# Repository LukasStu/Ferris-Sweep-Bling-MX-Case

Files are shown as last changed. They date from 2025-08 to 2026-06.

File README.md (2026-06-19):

# Ferris Sweep Bling MX Case

Fully enclosed, parametric OpenSCAD case for the Ferris Sweep (MX), built for clean looks, practical assembly, and solid acoustics.

This project targets makers who already know keyboard basics, so the guide focuses on the case-specific decisions and build flow.

## V2.1.0 Highlights

- Complete architecture refactor with dedicated top and bottom trays.
- Gasket-mounted PCB via switch-plate tabs for better isolation and typing feel.
- Accessible USB-C opening without removing the case.
- Integrated slider and reset access support.
- Heat-set insert bottom mounting for repeatable service and teardown.

## Gallery

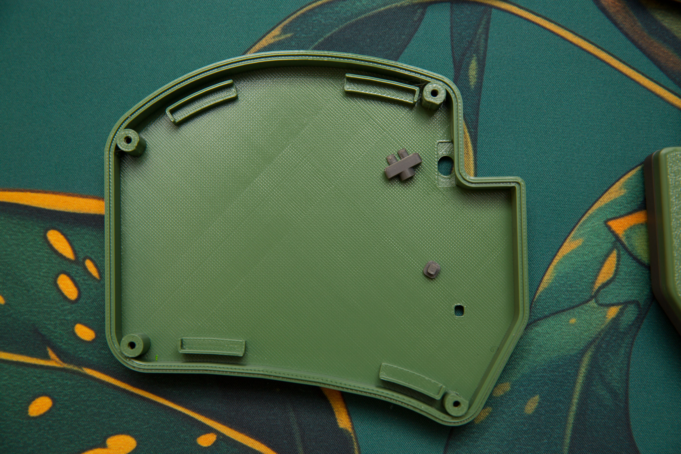
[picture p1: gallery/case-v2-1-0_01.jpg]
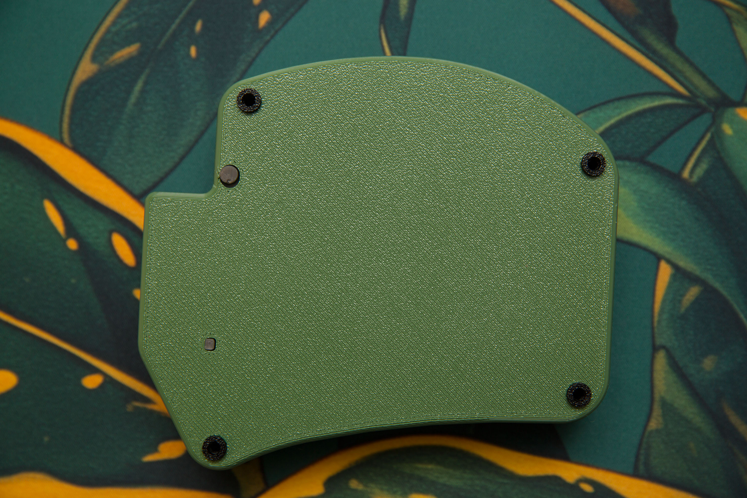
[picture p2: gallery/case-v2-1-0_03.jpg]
|  |  |
|---|---|
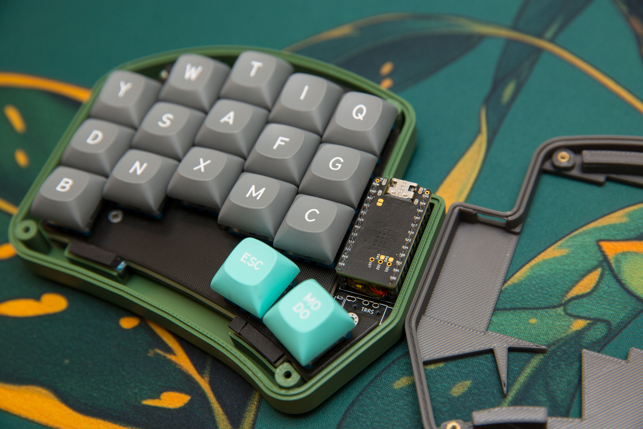
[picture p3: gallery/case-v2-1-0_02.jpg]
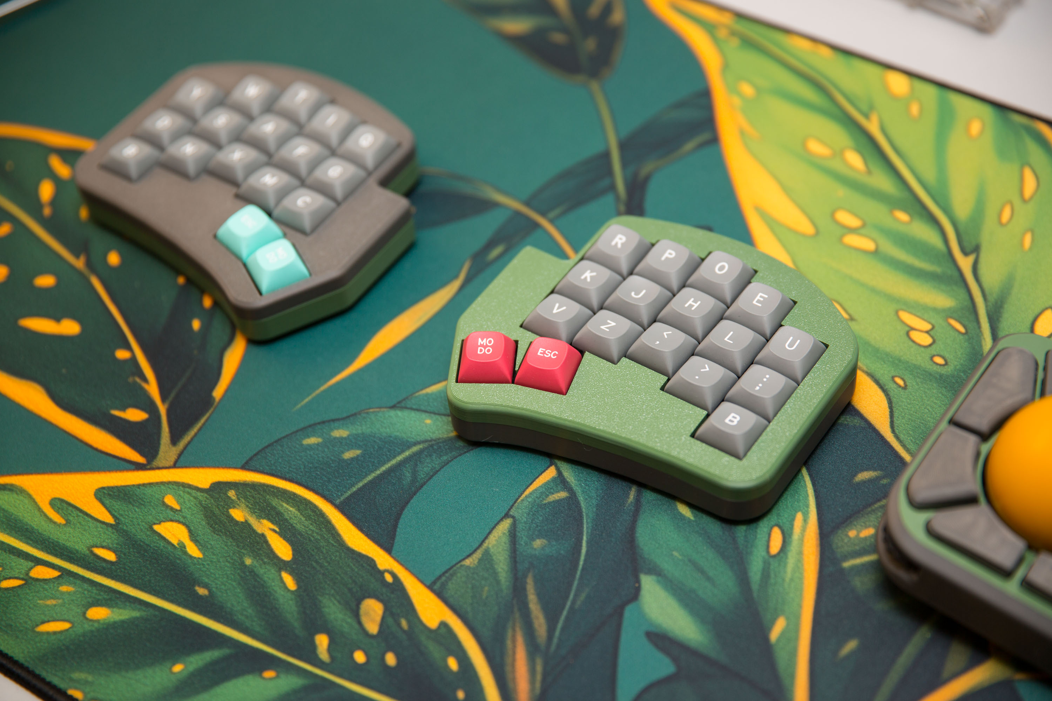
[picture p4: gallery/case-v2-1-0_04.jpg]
|  |  |
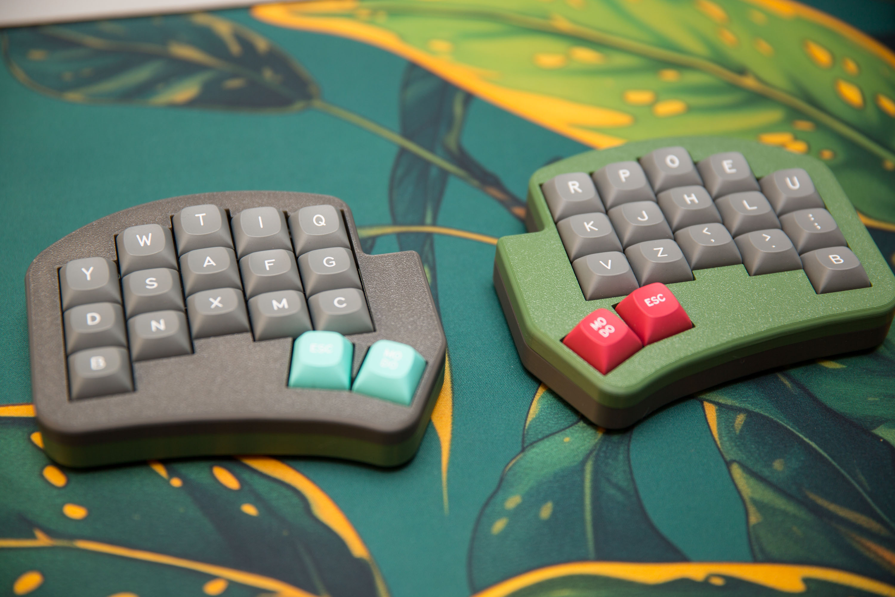
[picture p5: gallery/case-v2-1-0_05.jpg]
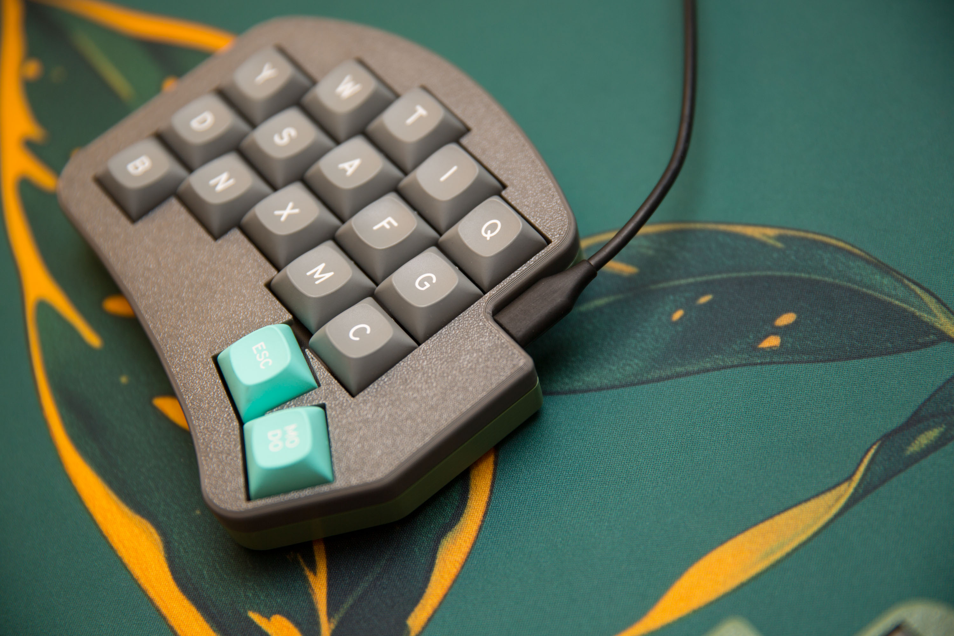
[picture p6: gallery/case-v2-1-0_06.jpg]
|  |  |

## MakerWorld

Download the latest release here:

[Ferris Sweep Bling MX Case v2.1.0 - MakerWorld](https://makerworld.com/de/models/2952710-ferris-sweep-bling-mx-case-v2-1-0#profileId-3308661)

## Repository Contents

- `case/case.scad` - main parametric model.
- `case/ferris_sweep_bling_mx.dxf` - reference 2D geometry.
- `gallery/` - build photos and reference images.

## Print Recommendations

- Material:
  - PLA/PETG for top and bottom case parts.
  - TPU for feet
- Supports:
  - Use tree supports on upper and lower parts for screw holes and USB opening.
- Usual quality baseline:
  - 0.2 mm layers, 1 to 2 walls, 15% to 25% infill.

## Hardware

- M2 heat-set inserts for the bottom mount points.
- Matching M2 screws for lid attachment.
- Ferris Sweep MX PCB including fr4 switchplate.

Heat-set and screw dimentions can be parameterized.

## Build Flow

1. Print case parts and clean support interfaces.
2. Install heat-set inserts in the top mounting points.
3. Test-fit PCB and confirm USB opening alignment before final assembly.
4. Close case with M2 screws and verify key travel/reset access.
5. Install TPU feet; Screws should still be accessable through hole.

## Wired Build Option

For a wired build, enable TRRS cutouts in both halves by uncommenting `trrs_cutout();` in:

- `top_case()`
- `bottom_case()`

If you are not using a power switch, comment out the power-switch cutouts.

## Adjusting USB Height and Outlet Alignment

USB-C position depends on your PCB/controller stack-up. In `case.scad`, two parameters control alignment:

### 1) `pcb_usb_distance`

- Definition: Distance in mm from PCB surface to USB-C port center.
- Purpose: Aligns the case outlet with the connector.
- How to measure: Measure from PCB top face to the middle of the USB-C shell.

<p align="center">
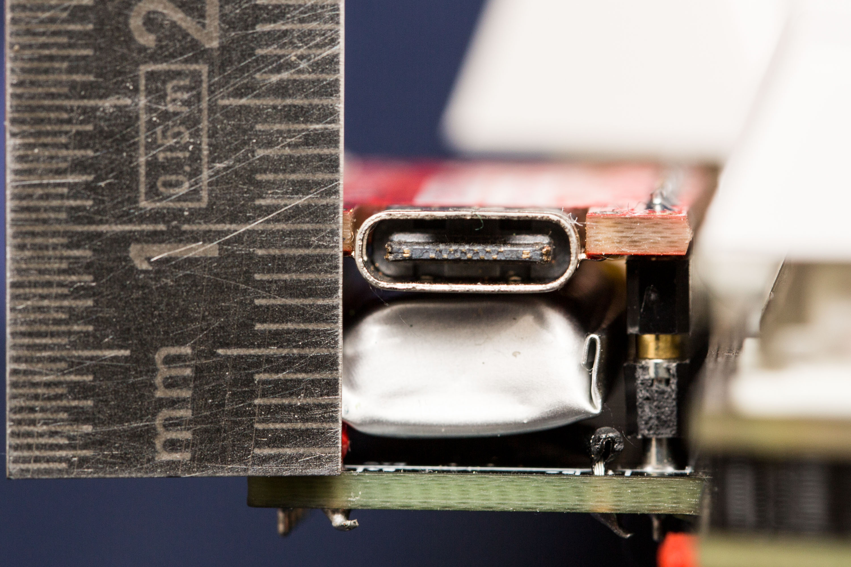
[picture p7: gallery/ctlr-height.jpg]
Measuring PCB to USB-C port distance
  <br>
  <em>Example: 9 mm from PCB to USB-C center</em>
</p>

### 2) `controller_wall_thickness` (optional)

- Definition: Wall thickness above the controller area near the USB opening.
- Default: `controller_wall_thickness = 1`.
- Use case: Increase if the wall is too thin for your controller placement.

### Parameter Example

```scad
pcb_usb_distance = 9;
controller_wall_thickness = 1.5;
```

Tip: print a short USB/controller test section first if your setup differs from common Ferris Sweep builds.

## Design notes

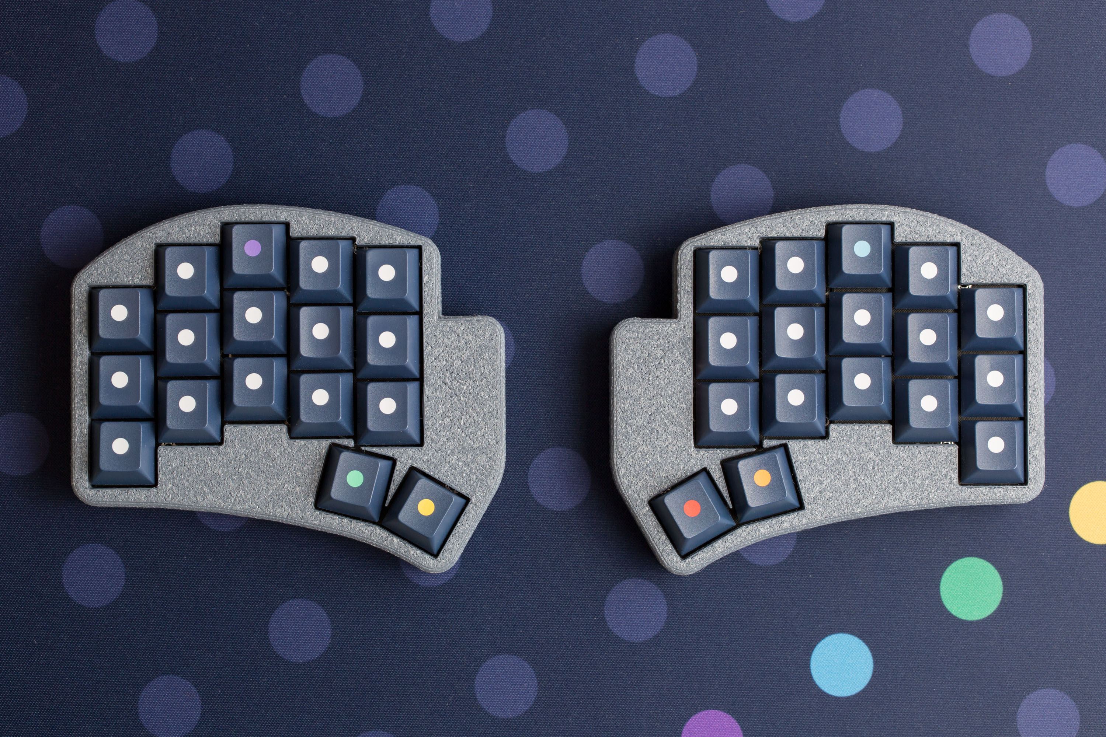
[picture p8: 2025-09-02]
gallery/case_05.jpg

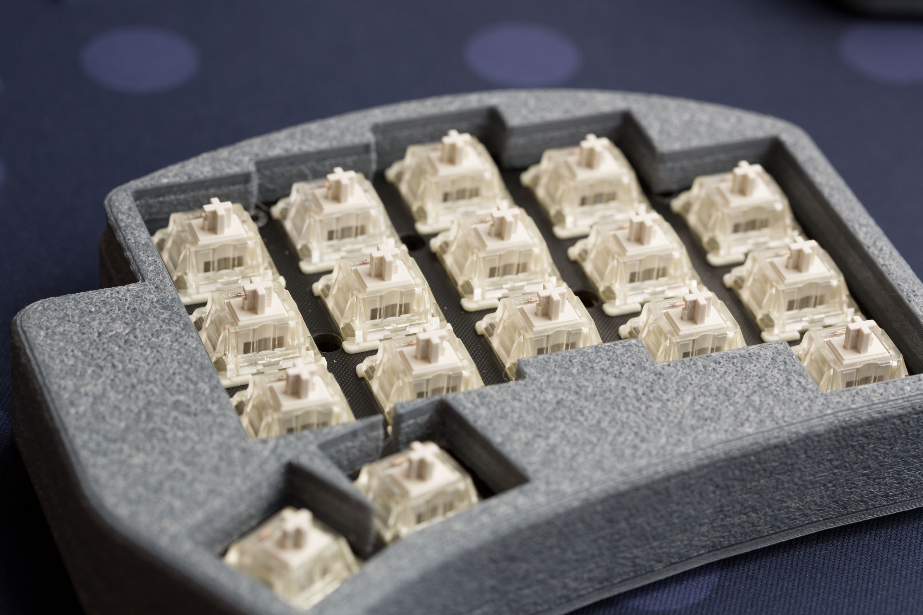
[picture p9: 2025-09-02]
gallery/case_04.jpg

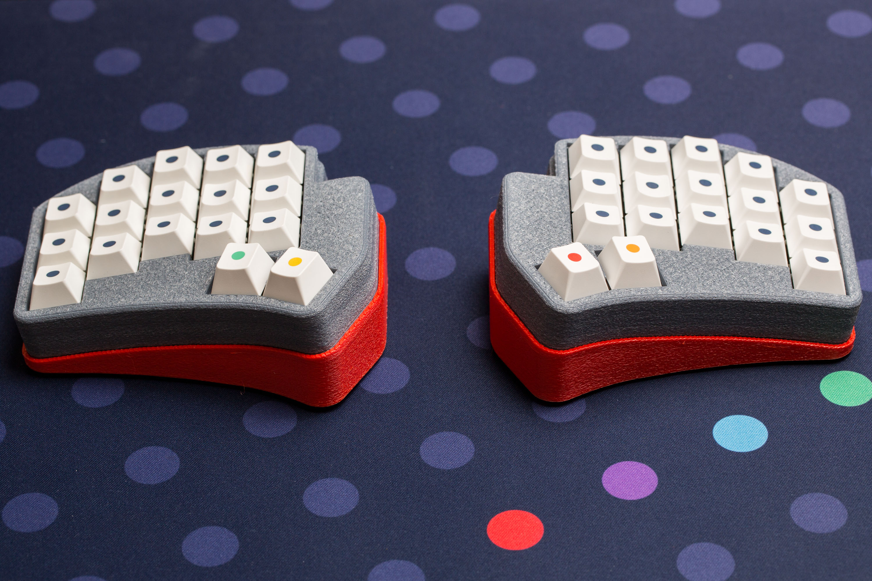
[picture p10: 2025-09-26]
gallery/tent_01.jpg

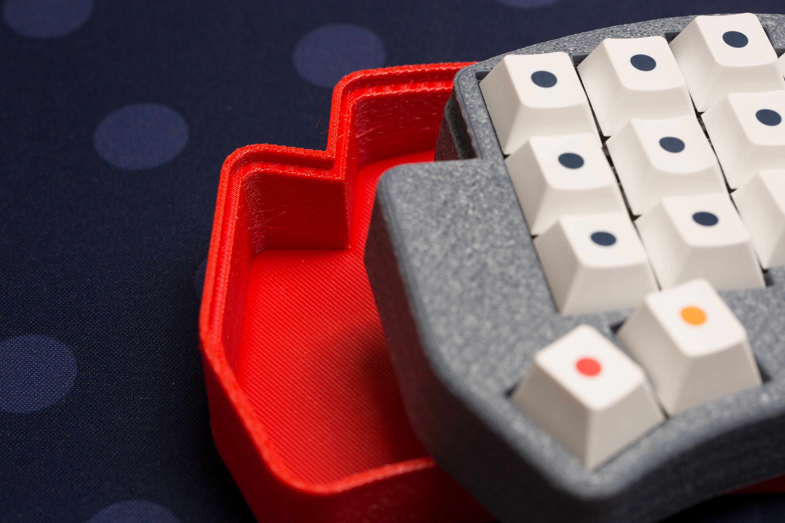
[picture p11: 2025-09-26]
gallery/tent_02.jpg

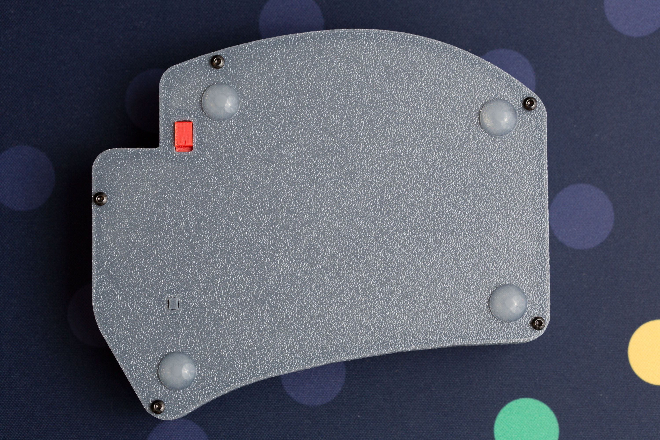
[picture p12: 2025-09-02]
gallery/case_03.jpg

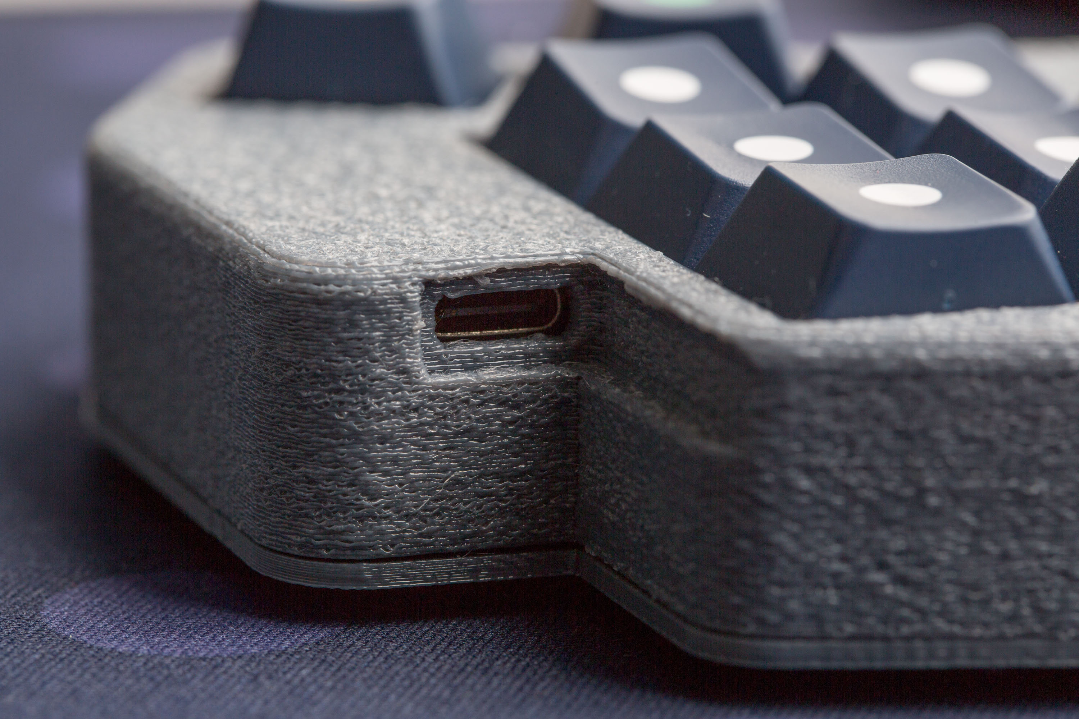
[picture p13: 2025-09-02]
gallery/case_02.jpg

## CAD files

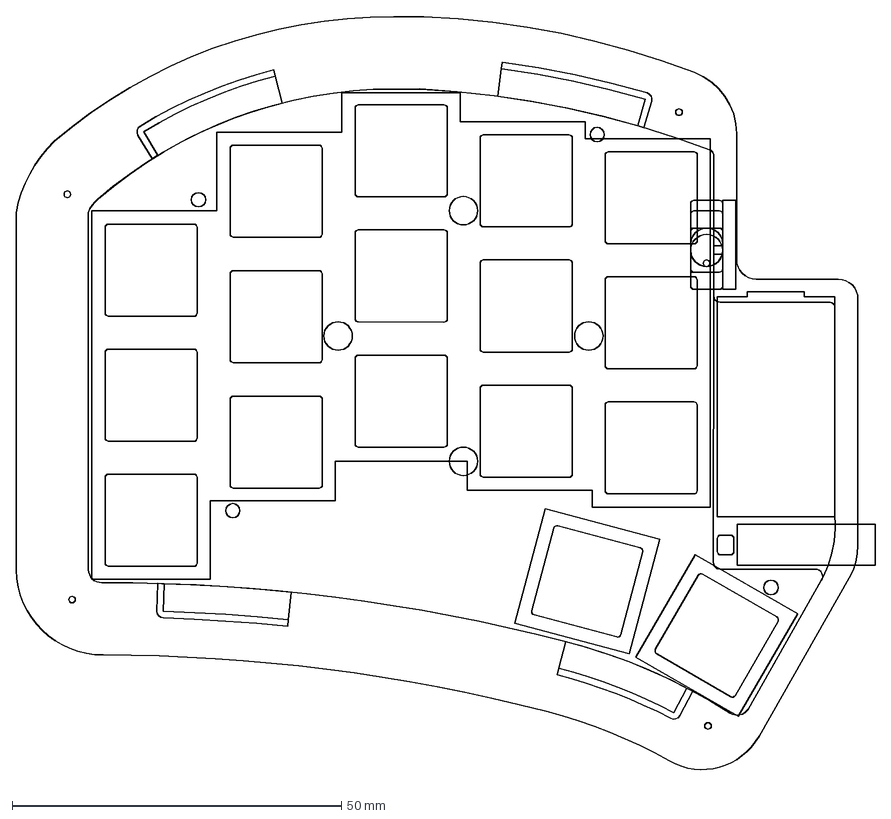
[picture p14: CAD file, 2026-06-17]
case/ferris_sweep_bling_mx.dxf
130.5 x 115.9 mm

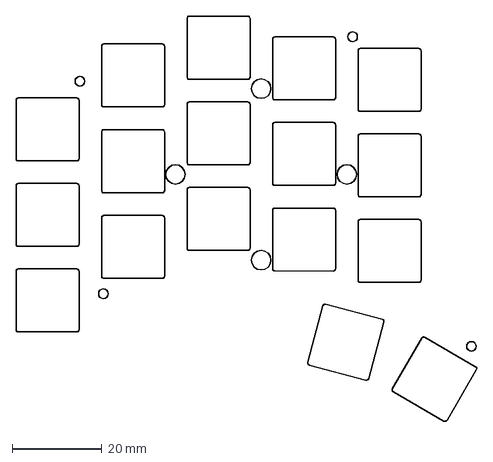
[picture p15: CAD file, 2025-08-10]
case/spacer/keys.dxf
102.4 x 90.1 mm

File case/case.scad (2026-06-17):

// -----------------------------------------------------------------------------
// Ferris Sweep MX Case Generator
// Author: Lukas Stürmlinger
// Requires: OpenSCAD 2021+ and ferris_sweep_bling_mx.dxf in the same directory.
// Description: Builds top/bottom shells, switch-plate foam, slider, reset button,
//              and optional tent support by extruding DXF layers via extrude_layer().
// Usage: Set PART to "top_case", "bottom_case", etc., then F6 to render.
// Notes: All dimensions in millimeters; DXF layers listed below must be kept in sync.
// CI: Every push triggers .github/workflows/build-stls-on-push.yml to render all STLs via GitHub Actions.
// -----------------------------------------------------------------------------
$fn = 100;

// Dimensions & geometry
// -------------------- Parameters --------------------
// top case
fillet_radius = 2.5;
top_case_thickness = 3;
case_wall_thickness = 3;
controller_cover_thickness = 1;
keycaps_gap = 0.5;
keycaps_cutout_height = 8.5;
decoration_cutout_depth = 1.0;

// bottom case
bottom_thickness = 2;
bottom_gap = 1.5;

// rim
rim = 0.5;
rim_height = 1;
rim_clear = 0.2;

// PCB + plate
kailh_sockets_thickness = 2;
fr4_thickness = 1.6;
switch_plate_foam_thickness = 3.3;

// gasket
gasket_thickness = 2;
compression = 0.5;
compressed_gasket_thickness = gasket_thickness * (1 - compression);
gasket_rim = 1.5;

// switches
switch_protrusion = 1;
slider_immersion_depth = 0.5;
slider_total_height =
  switch_protrusion + bottom_thickness + bottom_gap + kailh_sockets_thickness + fr4_thickness - 0.5;
MSK_thickness = 1.4;
B3U_thickness = 1.6;

// USB
w_shell = 8.94;
h_shell = 3.26;
r_corner = 1.2;
pcb_usb_distance = 9;
Z_USB = h_shell / 2 + bottom_gap + kailh_sockets_thickness + fr4_thickness + pcb_usb_distance;
usb_main_offset = [ 139.9, -76, Z_USB ];
usb_tunnel_offset = [ 139.9, -28, Z_USB ];
usb_tunnel_len_mm = 50;

// Screw positions & sizes
heat_sink_insert_diameter = 2.7;
heat_sink_insert_depth = 3.1;
screw_diameter = 2.5;
thread_length = 4;
head_diameter = 4.5;
thread_intrusion = 2;
screw_support_diameter = 7;
screw_marker_diameter = 1;

// Rubber feet
insert_height = 3;
foot_height = 1.5;
hollow_diameter = head_diameter - 0.9;

// Clearances
clear_pcb_mm = 1.0;
clear_gasket_mm = 0.5;
clear_usb_mm = 0.5;
clear_switch_mm = 0.2;
screw_support_clearance = 0.2;

// Derived Heights
z_bottom_gap = bottom_thickness;
z_kailh_sockets = z_bottom_gap + bottom_gap;
z_pcb = z_kailh_sockets + kailh_sockets_thickness;
z_switchplate_foam = z_pcb + fr4_thickness;
z_switchplate = z_switchplate_foam + switch_plate_foam_thickness;
z_keycaps_cutout = z_switchplate + fr4_thickness;

// bases and tops
z_bottom_case_top = z_keycaps_cutout;
z_top_case_base = z_bottom_case_top;
z_top_case_top = z_bottom_case_top + keycaps_cutout_height;

// Derived
total_height_bottom_case = z_keycaps_cutout;
total_height_top_case = keycaps_cutout_height;

// Single DXF file + layer names
DXF = "ferris_sweep_bling_mx.dxf";

L_pcb_outline = "pcb_outline";
L_outer_shape = "outer_shape";
L_outer_shape_decor = "outer_shape_decor";
L_decor_lines = "decor_lines";
L_keycaps_outline = "keycaps_outline";
L_controller_cutout = "controller_cutout";
L_reset = "reset";
L_pwr_lid_cutout = "pwr_lid_cutout";
L_pwr_body = "pwr_body";
L_pwr_circ = "pwr_circ";
L_pwr_body_support = "pwr_body_support";
L_pwr_knob_cutout = "pwr_knob_cutout";
L_pwr_body_overhang = "pwr_body_overhang";
L_pwr_overhang_cutout = "pwr_overhang_cutout";
L_pwr_on_label = "pwr_on_label";
L_switches = "switches";
L_switchplate_outline = "switchplate_outline";
L_gasket_supports = "gasket_supports";
L_gasket_supports_rim = "gasket_supports_rim";
L_screw_markers = "screw_markers";
L_trrs = "trrs";

// -----------------------------------------------------------------------------
// ------------------------------- Helpers -------------------------------------
// -----------------------------------------------------------------------------

module extrude_layer(layer, z = 0, h = 1, delta = 0) {
  translate([ 0, 0, z ]) linear_extrude(height = h) offset(delta = delta) import(file = DXF, layer = layer);
}

module screw_hole_layer(z = 0, h = 1, target_diameter = screw_marker_diameter) {
  marker_delta = (target_diameter - screw_marker_diameter) / 2;
  extrude_layer(L_screw_markers, z = z, h = h, delta = marker_delta);
}

// -----------------------------------------------------------------------------
// ------------------------------ Top und bottom basics ------------------------
// -----------------------------------------------------------------------------

module outer_shape_top() {
  difference() {
    union() {
      extrude_layer(L_outer_shape, z = z_top_case_base, h = fillet_radius);
      minkowski() {
        sphere(fillet_radius);
        translate([ 0, 0, z_top_case_base + fillet_radius ])
            extrude_layer(L_outer_shape, h = total_height_top_case - 2 * fillet_radius, delta = -fillet_radius);
      }
    }
    extrude_layer(L_outer_shape, z_top_case_base, h = total_height_top_case - top_case_thickness,
                  delta = -case_wall_thickness);
  }
}

module outer_shape_bottom() {
  difference() {
    union() {
      extrude_layer(L_outer_shape, z = fillet_radius, h = total_height_bottom_case - fillet_radius);
      minkowski() {
        sphere(fillet_radius);
        translate([ 0, 0, fillet_radius ])
            extrude_layer(L_outer_shape, h = total_height_bottom_case - 2 * fillet_radius, delta = -fillet_radius);
      }
    }
    extrude_layer(L_outer_shape, z = z_bottom_gap, h = total_height_bottom_case - bottom_thickness,
                  delta = -case_wall_thickness);
  }
}

module case_rim(delta = 0) {
  difference() {
    extrude_layer(L_outer_shape, z = z_bottom_case_top, h = rim_height + delta,
                  delta = -case_wall_thickness / 2 + rim / 2 + delta / 2);
    extrude_layer(L_outer_shape, z = z_bottom_case_top, h = rim_height + delta,
                  delta = -case_wall_thickness / 2 - rim / 2 - delta / 2);
  }
}

// -----------------------------------------------------------------------------
// ------------------------------ Top und bottom basics ------------------------
// -----------------------------------------------------------------------------

module upper_gasket_taps() {
  difference() {
    extrude_layer(L_gasket_supports, z = z_switchplate + compressed_gasket_thickness,
                  h = fr4_thickness + keycaps_cutout_height - decoration_cutout_depth - compressed_gasket_thickness,
                  delta = 0.2);
    extrude_layer(L_pcb_outline, z = z_switchplate + compressed_gasket_thickness,
                  h = fr4_thickness + keycaps_cutout_height - decoration_cutout_depth - compressed_gasket_thickness,
                  delta = 0.2);
  }
}

module lower_gasket_taps() {
  difference() {
    extrude_layer(L_gasket_supports, z = z_bottom_gap,
                  h = bottom_gap + kailh_sockets_thickness + fr4_thickness - compressed_gasket_thickness);
    extrude_layer(L_pcb_outline, z = z_bottom_gap,
                  h = bottom_gap + kailh_sockets_thickness + fr4_thickness - compressed_gasket_thickness,
                  delta = clear_gasket_mm);
  }
}

module lower_gasket_taps_rims() {
  difference() {
    extrude_layer(L_gasket_supports_rim, z = z_bottom_gap,
                  h = bottom_gap + kailh_sockets_thickness + fr4_thickness + compressed_gasket_thickness + gasket_rim);
    extrude_layer(L_pcb_outline, z = z_bottom_gap,
                  h = bottom_gap + kailh_sockets_thickness + fr4_thickness + compressed_gasket_thickness + gasket_rim,
                  delta = clear_gasket_mm);
  }
}

module keycaps_cutout() {
  extrude_layer(L_keycaps_outline, h = z_top_case_top, delta = 2 * keycaps_gap);
}

module controller_cutout() {
  extrude_layer(L_controller_cutout, h = z_top_case_top - controller_cover_thickness, delta = clear_usb_mm);
}

// -----------------------------------------------------------------------------
// ------------------------------ Buttons, Switches, USB------------------------
// -----------------------------------------------------------------------------

module pwr_switch_slider_cutout(delta = 0) {
  extrude_layer(L_pwr_lid_cutout, h = bottom_thickness, delta = delta);
}

module power_switch_overhang_cutout(delta = 0) {
  extrude_layer(L_pwr_overhang_cutout, z = bottom_thickness - slider_immersion_depth, h = slider_total_height,
                delta = delta);
}

module power_switch_slider() {
  body_h = MSK_thickness + compressed_gasket_thickness + 1;
  overhang_h = slider_immersion_depth + bottom_gap + kailh_sockets_thickness + fr4_thickness - MSK_thickness -
               compressed_gasket_thickness - 0.5;
  body_z = z_bottom_gap + overhang_h;
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

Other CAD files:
case/round-edges-tests.scad

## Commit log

2025-08-13 remove unused spacer
    [sweep-bling-mx__plate-Edge_Cuts.dxf, switch-plate-3-3.scad, switch-plate-3-3.stl]
2025-08-13 reorganize spacer
    [keys.dxf, outline.dxf, tpu_spacer.3mf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]
2025-08-13 add bottom spacer
    [bottom_spacer.scad, bottom_spacer.stl]
2025-08-13 add indicator to power switch
    [case.scad, pwr_switch.stl, slider_label.dxf]
2025-08-13 add build selector for modular case assembly
    [case.scad]
2025-08-27 Refactor code structure for improved readability and maintainability
    [bottom_case.stl, bottom_spacer.scad, bottom_spacer.stl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]
2025-08-27 update README with download link and remove obsolete 3D model files
    [bottom_case.3mf, switches.3mf, top_case.3mf]
2025-09-17 format case.scad
    [case.scad]
2025-09-17 remove unused header
    [case.scad]
2025-09-17 add tenting case
    [case.scad]
2025-10-30 add controller_wall_thickness as parameter
    [case.scad]
2026-06-11 convert to gasket mount
    [case.scad, ferris_sweep_bling_mx.dxf]
2026-06-16 tweak power slider switch
    [case.scad]
2026-06-17 add basic trrs cutout
    [case.scad, ferris_sweep_bling_mx.dxf]
2026-06-17 add instructions for enabling TRRS cutouts in wired builds
2026-06-17 add v2.1.0 gallery and wired build note
2026-06-17 add short 3d printing hint
